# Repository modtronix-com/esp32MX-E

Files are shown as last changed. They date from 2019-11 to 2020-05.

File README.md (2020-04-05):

# esp32MX-E
This repository contains [documentation](docs), [examples](examples), [schematic, PCB files](pcb) and other information for the Modtronix esp32MX-E board. This board was initially launched on [Crowd Supply](https://www.crowdsupply.com/modtronix/esp32mx-e). It can be [ordered online](https://www.modtronix.com/esp32mx-e) from Modtronix<br>

After that, it will be available on www.modtronix.com, and most likely also for sale at www.mouser.com

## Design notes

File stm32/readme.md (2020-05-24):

This folder contains STM32 projects.
- The "default_ws" folder is a workspace for the STM32CubeIDE. It contains a single
  project named "default". This contains the default firmware for the STM32F030

## Modify STM32 project ##
To modify, build and program a STM32 project:
- Download and install the [STM32CubeIDE](https://www.st.com/en/development-tools/stm32cubeide.html).
- Start STM32CubeIDE, and select the "default_ws" folder as the workspace
- Select "File"->"Import" from the menu, and select "Existing project into workspace"
- Select the "default" project. In "Options" ensure "Copy project into workspace" is NOT selected
- Import project

This will import the "default" project into the workspace. It should now be possible to build the project, and program the STM32F030.

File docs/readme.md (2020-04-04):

Documentation for the Modtronix esp32MX-E board.

The esp32MX-E is a versatile ESP32 based board with support for Ethernet, WiFi, Bluetooth, USB Type C, and more. It is designed with ease-of-integration in mind, so you can use it to simplify and accelerate the development of your own custom boards. 

# Schematics & Dimensions
The esp32MX-E schematics & dimensions are available in the "images" folder:
- [Schematics Page1](../images/esp32MX-E_schematics_pg1.png?raw=true)
- [Schematics Page2](../images/esp32MX-E_schematics_pg2.png?raw=true)
- [Dimensions](../images/esp32MX-E_dimensions.png?raw=true)

# Power
The esp32MX-E has an advanced power supply circuit that accommodates multiple inputs, provides 3.3 V and 5 V outputs, and delivers over 2 A of current to the user. It has high current switch mode regulators, at both 3.3 V and 5 V, to ensure low power consumption and high efficiency. Power can be supplied via the USB C connector, a 2.1 mm barrel connector, or the external power supply pin. This allows board designers to integrate the esp32MX-E as a daughterboard and get 3.3 V, 5 V, and supply voltage via the pin header connector.

# Reliability
Capacitors, in particular, are often the cause of failure in electronic devices. We have sourced the capacitors in esp32MX-E from reputable manufacturers like Panasonic, Samsung, Murata, TDK, and Yageo. Furthermore, all of our capacitor voltages are overrated by at least 190%.

# User I/O
esp32MX-E has a secondary 32-bit ARM processor (STM32F030F4) that serves by default as an I²C port expander. If required, you can program this secondary microcontroller with custom firmware.

# Features & Specifications

- **esp32 Module**
    - 32-bit LX6 microprocessor operating at 160 or 240 MHz
    - 4 MB Flash
    - 520 KB SRAM
- **Storage**: Micro SD card slot
- **Wi-Fi**: 802.11 b/g/n
- **Bluetooth**: v4.2 BR/EDR & BLE
- **USB**: Type C connector
    - Virtual COM port via USB
    - Programmable via USB
    - Power via USB
- **User I/O**:
    - 22 pins of which 4 are inputs only.
    - Four 5 V tolerant I/O pins
    - Not all I/Os are available when the SD Card is used
    - Programmable pull-up and pull-down resistors on most inputs
- **Secondary Processor**: I²C I/O expander implemented with a user programmable STM32F030F4
- **Expansion Pin Headers**: Two standard 2.54 mm (0.1") expansion pin headers
    - One with 14 pins (2x7)
    - One with 20 pins (2x10)
- **Power Supply**: Switch Mode
    - 5 V, over 2 A of current for user applications
    - 3.3 V, over 2 A of current for user applications
- **Power Sources**:
    - USB Type C connector
    - 2.1 mm barrel connector
    - Vx external power supply pin
- **Supply Voltage**: 4.5 V to 16 V (via 2.1 mm Barrel connector or Vx pin)
- **Operating Temperature**:
    - Standard version: 0° C to 85° C
    - Industrial version: -40° C to 85° C
- **Physical Controls**:
    - User LED
    - Button
- **Compact Size**: 64.4 mm x 42 mm (2.54" x 1.65")
- **Enclosure**: Optional

# Integration into Custom Hardware
Designed both for standalone use and for integration into larger projects, esp32MX-E has two female headers, so you can plug a small expansion board into it or use esp32MX-E itself as a daughterboard. All connectors, switches and LEDs are on one side of the board, which makes it far easier to design custom enclosures.

We supply raised male headers, for when esp32MX-E is used as a daughterboard, that provide 14.5 mm of space between it and the baseboard. A single board spacer and a screw are all you need for a secure fit, and we provide both a threaded and a non-threaded 14.5 mm spacer. Two additional screw holes are available, but are not required when using esp32MX-E as a daughterboard.

The Eagle Schematics and PCB files for all prototype boards and faceplates are available in [in the PCB folder](../pcb).

| | |
| --- | --- |
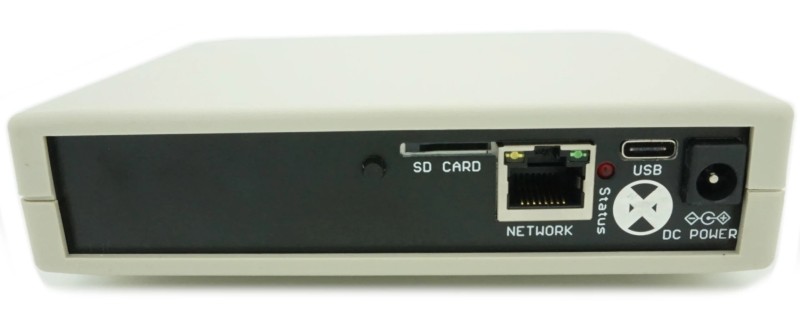
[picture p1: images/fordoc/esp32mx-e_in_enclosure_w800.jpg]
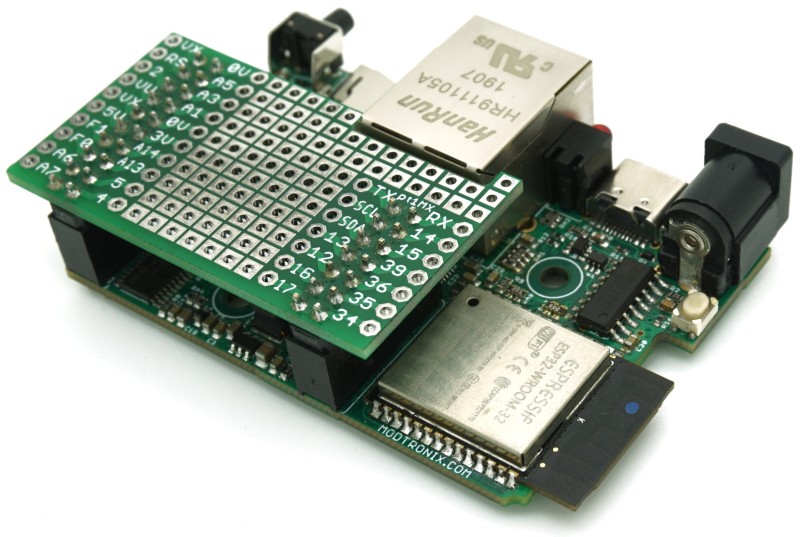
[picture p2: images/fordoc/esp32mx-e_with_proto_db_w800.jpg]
|  |  |
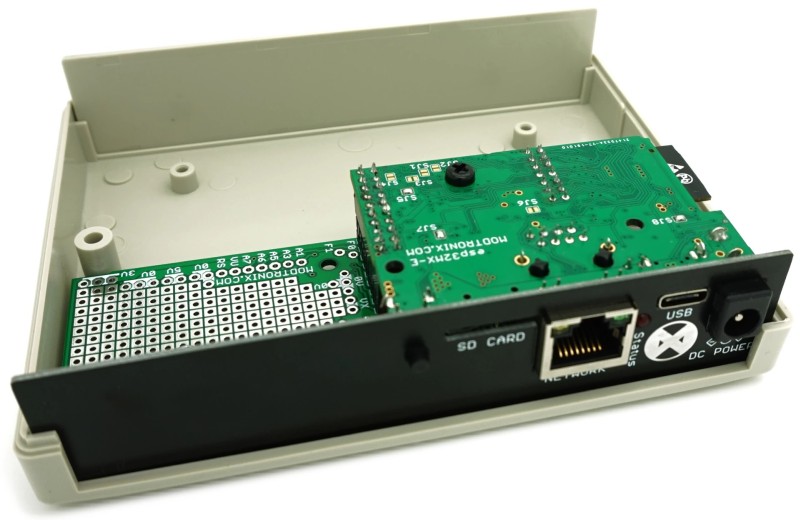
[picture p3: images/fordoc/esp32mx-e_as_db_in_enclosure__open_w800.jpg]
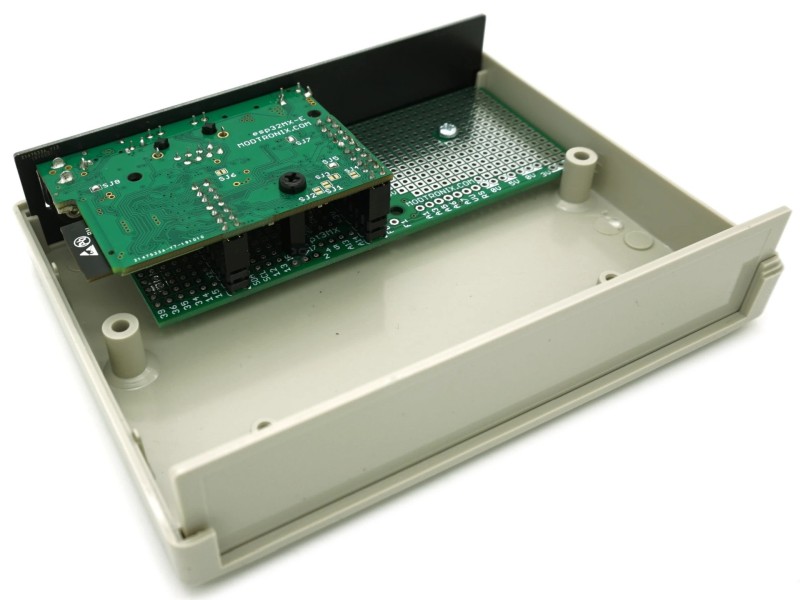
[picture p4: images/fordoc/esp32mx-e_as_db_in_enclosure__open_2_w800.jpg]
|  |  |

# Software Development
The two most popular ways to develop software for the esp32MX-E is using the official "Espressif ESP-IDF" or Arduino. The Arduino option is by far the easyest to get started. But, ESP-IDF provided many more options, and a true RTOS environment.

## Espressif ESP-IDF
For details to use the official ESP-IDF with the esp32MX-E, see [the "idf" examples folder](../examples/idf/README.md).

## Arduino
For details to use the official ESP-IDF with the esp32MX-E, see [the "idf" examples folder](../examples/arduino/README.md).

# STM32F030 Secondary Microcontroller
The esp32MX-E has a secondary STM32F030F4 microcontroller. It controls the PHY reset circuitry, and provides additional I/O via the the I2C port of the ESP32. It can also be programmed with custom firmware.

## Programming the STM32F030
The STM32F030F4 can be programmed via the following methods:
- Serial Port Bootloader
- ST-Link programmer
- By the host ESP32
See below for details.

### Serial Bootloader
The STM32 microcontroller has a built in serial(UART) bootloader, that is activated by pressing the user button while applying power to the esp32MX-E board. Once in the bootloader mode, we need a method to connect to the UART on the STM32. A simple way to do this is to have software on the ESP32 act as a bridge between the STM32 and virtual comm port chip. This enables us to use the STM32CubeProgrammer (STM32CubeProg) to program the STM32 via the UART. For this to work, the UART on the ESP32 has to be configured for 115200 baud, **even** parity, and 1 stop bit.

After programming the STM32 with the STM32CubeProgrammer, we can use this same setup to communicate with the UART on the STM32 via a serial port terminal. This is very useful for debugging. **Note** that the UART on the STM32 has to be configured for 115200 baud, **even** parity, and 1 stop bit. This is to match the settings required by the STM32CubeProgrammer, and which we used for our ESP32 bridge firmware.

### ST-Link Programmer
To program an STM32 chip using a ST-Link programmer, we need to connect the GND, Reset, SWDIO and SWCLK of the STM32 chip to the corresponding pins of the ST-Link programmer. These pins are all available available on the pin header of the esp32MX-E.

To get access to the UART on the STM32 during programming and debugging, we can use one of the following methods:
- Configure pins PA9 and PA3 of the STM32 as the UART TX and RX pins. These pins are available via the SCL(conected to PA9 of STM32) and PA3 pins on the pin header of the esp32MX-E board. When using the ST-Link V3, these pins can be connected to the RX and TX pins of the ST-Link programmer
- Configure pins PA9 and PA10 of the STM32 as the UART TX and RX pins. Then, program the ESP32 with firmware that acts as a bridge between the STM32 UART and USB virtual comm port chip. This will enable communicating with the STM32's UART via the USB virtual comm port.

### ESP32 programming the STM32
It is possible for the ESP32 to directly program the STM32 via it's UART bootloader. The ESP32 is connected to the STM32 via I2C. We have to add an I2C command to put the STM32 into bootloader mode. After doing this, the ESP32 will reconfigure the I2C pins connected to the STM32 to a UART. This is possible, seeing that the I2C and UART of the STM32F030 use the same pins. So, during normal operation, these pins on the STM32 are I2C pins, and when starting the STM32 in bootloader mode, they are UART pins.

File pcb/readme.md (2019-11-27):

This folder contains Eagle PCB and Schematic files. They are all provided for fee, as is. We take no responsibility for any errors
or defects.

The folders contains the following.

# pt1mx
This folder contains a small prototype PCB that first onto the 2 female headers of the esp32MX-E board.

| | |
| --- | --- |
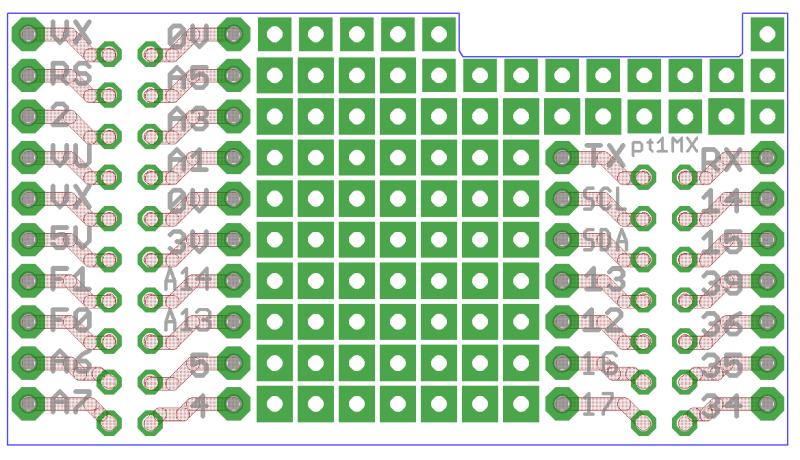
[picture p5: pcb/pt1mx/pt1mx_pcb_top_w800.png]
|  | Image of pt1mx |

# pt2mx
This folder contains a larger prototype PCB that first onto the 2 female headers of the esp32MX-E board.
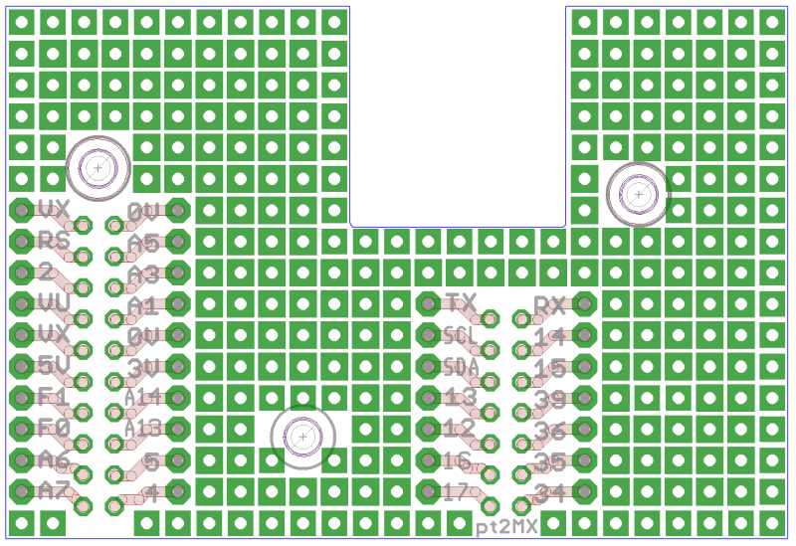
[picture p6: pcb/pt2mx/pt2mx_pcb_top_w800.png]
Image of pt2mx


# pt3mx
This folder contains a baseboard for the esp32MX-E board. It is designed to be used with raised 2x7 and 2x10 male
pin headers(standard 0.1" = 2.54mm spacing). We use 14.5mm raised headers, and also have 14.5mm high PCB spacers
available. It fits into the Hammond RM2015S enclosure. The "fp_pt3mx" front panel can be used with the RM2015S
enclosure.

| | |
| --- | --- |
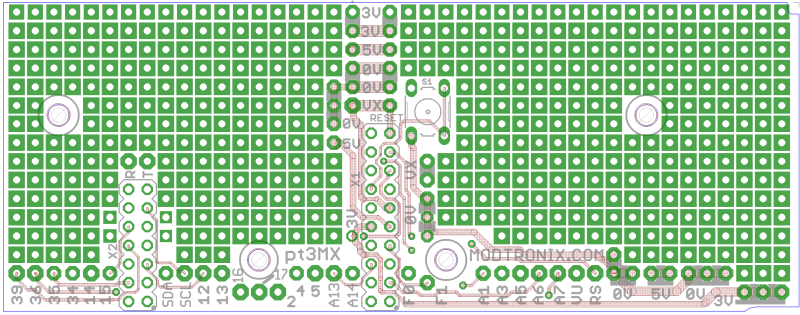
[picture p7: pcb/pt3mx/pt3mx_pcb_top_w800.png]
Image of pt3mx
|  | Image of pt1mx |

# fpan-mxe
This folder contains the frontpanel used when the esp32MX-E is used together with the pt3mx(or custom board) baseboard, and the RM2015S
enclosure. This frontpanel is a standard PCB (1 or 2 layers), with black solder mask. By default, we get them manufactured using HASL(Hot Air Solder Level) surface finish. For a bit extra, you can get it manufactured with the ENIG(Immersion Gold) surface finish, which adds a premium look.

| | |
| --- | --- |
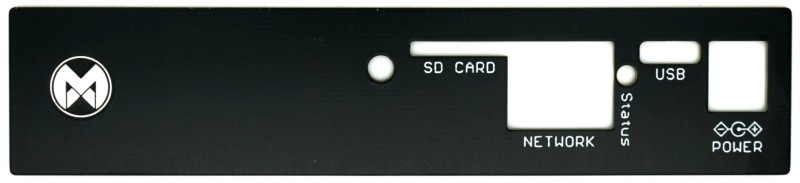
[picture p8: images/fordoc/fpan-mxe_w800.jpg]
Image of pt1mx
|  | Image of pt1mx |

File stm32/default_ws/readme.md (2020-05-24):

This folder is a [STM32CubeIDE](https://www.st.com/en/development-tools/stm32cubeide.html) workspace, containing a single project named "default". It contains the default firmware for the STM32F030

This code performs the following main functions:
- Monitors the ESP32 reset pin. If a reset is applied(via reset button on the esp32MX-E or USB programming), it resets the PHY chip(LAN8720)
- Checks when the ESP32 starts outputting the 50MHz PHY clock on the GPIO0 pin, and takes the PHY out of reset.

This the code monitors the GPIO0 pin of the ESP32. This pin will output the 50MHz PHY clock once the ESP32 is configured for Ethernet. If 200 or more pulses are found on the GPIO0 pin within 3ms, the PHY is taken out of reset. The reason we check for 200 pulses in 3ms is to enable GPIO0 to be used to blink the LED when Ethernet is NOT enabled. This allow the esp32MX-E board to be programmed with code that does not use Ethernet, and uses GPIO0 to blink the LED.

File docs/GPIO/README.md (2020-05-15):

# Pinouts & GPIO Pins #
For details on the ESP32 GPIO ports, see the [ESP32 GPIO](#esp32-gpio) section below.  
For details on the STM32F030 GPIO ports, see the [STM32F030 GPIO](#stm32f030-gpio) section below.
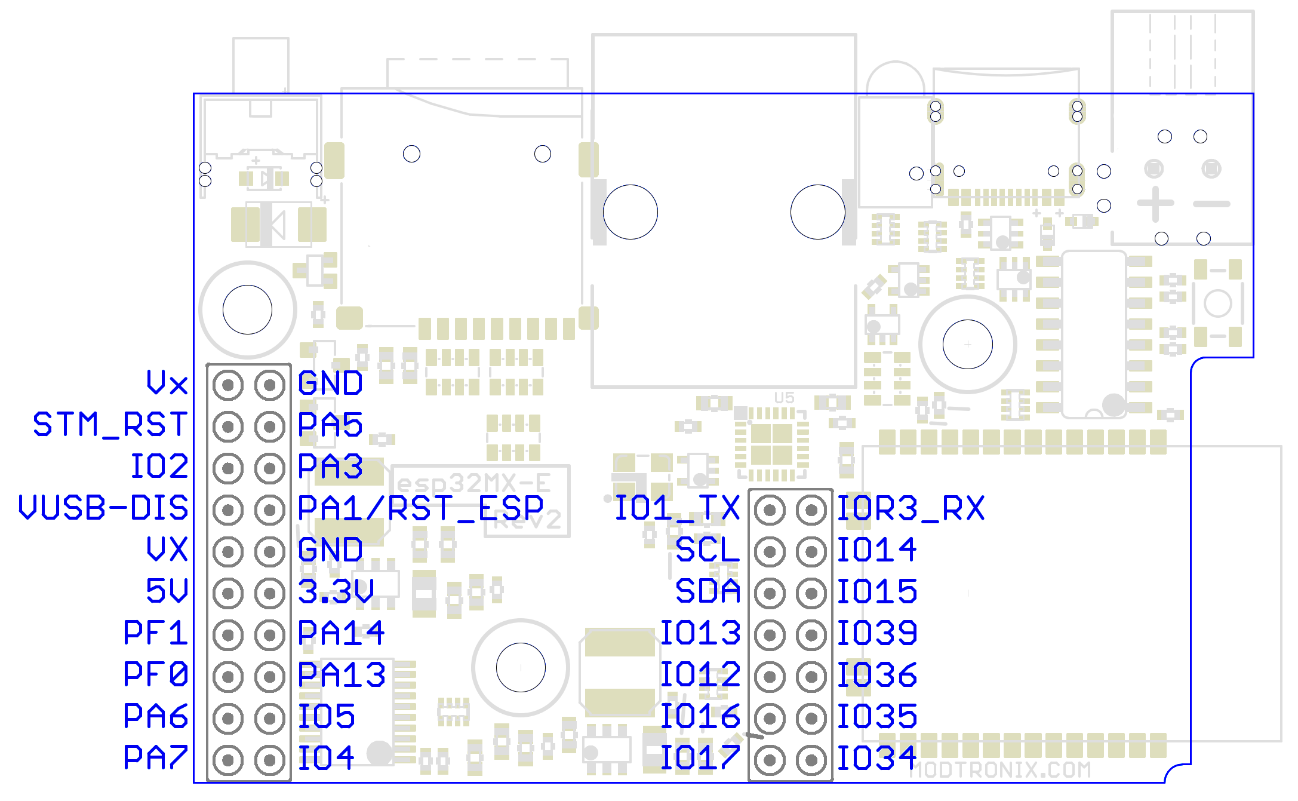
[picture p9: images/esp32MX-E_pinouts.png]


# ESP32 GPIO

| ESP32 Pin | Analog | DAC/T | Serial | Function | Note |
| --- | --- | --- | --- | --- | --- |
| GPIO0  | ADC2-1  | Touch-1 | | **NOT available** if Ethernet used, used by Bootloader and PHY | Default **Pull-Up**. Bootloader Mode=0, Run Mode=1 |
| GPIO1  | | | TX0 | **Available** if USB comm not used. USB TX.| On the ESP32-NodeMCU, this pin is used for the USB to Serial converter TX pin |
| GPIO2  | ADC2-2  | Touch-2 | | **Available** if SD not used. SD Card. 47k PU| Default **Pull-Down**. Must be 0 to enter Bootloader Mode (when GPIO0=0). |
| GPIO3  | | | RX0 | **Available** if USB comm not used. USB RX via jumper. | On the ESP32-NodeMCU, this pin is used for the USB to Serial converter RX pin |
| GPIO4  | ADC2-0  | Touch-0 | | **Available** to user. | | 
| GPIO5  | | | VSPI-SS | **Available** by default, LED via Jumper | Default **Pull-up**, use to determine timing of SDIO Slave. |
| GPIO12 | ADC2-5  | Touch-5 | MISO | **Available** to user. | **JTAG** TDI - Default **Pull-down**. If 1 at PU, sets flash = 1.8V, else standard 3.3V. **MUST be 0** at PU for 3.3V board! |
| GPIO13 | ADC2-4  | Touch-4 | MOSI | **Available** to user. | **JTAG** TCK |
| GPIO14 | ADC2-6  | Touch-6 | CLK | **Available** if SD not used.<br>SD Card.| **JTAG** TMS |
| GPIO15 | ADC2-3  | Touch-3 | SS | **Available** if SD not used.<br>SD Card.| **JTAG** TDO - Default **Pull-up**. If 0 at PU, silences boot messages printed by the ROM bootloader.|
| GPIO16 | | | RX2 | **Available** to user. | **NOT AVAILABLE** on Wrover, used for PSRAM CS ! |
| GPIO17 | | | TX2 | **Available** to user. | **NOT AVAILABLE** on Wrover, used for PSRAM CLK ! |
| GPIO18 | | | VSPI-CLK  | **NOT available**, used by PHY | |
| GPIO19 | | | VSPI-MISO | **NOT available**, used by PHY | |
| GPIO21 | | | I2C-SDA | **NOT available**, used by PHY | |
| GPIO22 | | | I2C-SCL | **NOT available**, used by PHY | |
| GPIO23 | | | VSPI-MOSI | **NOT available**, used by PHY | |
| GPIO25 | ADC2-8  | DAC 1 | | **NOT available**, used by PHY | |
| GPIO26 | ADC2-9  | DAC 2 | | **NOT available**, used by PHY | |
| GPIO27 | ADC2-7  | Touch-7 | | **NOT available**, used by PHY | |
| GPIO32 | ADC1-4  | Touch-9 | | I2C SCL, can also be<br> **used for user I2C** |  |
| GPIO33 | ADC1-5  | Touch-8 | | I2C SCL, can also be<br> **used for user I2C** |  |
| GPIO34 | ADC1-6  | | | **Available** by default,<br> User Button via Jumper | **Input Only!** No PU or PW! |
| GPIO35 | ADC1-7  | | | **Available** to user.<br> Input only | **Input Only!** No PU or PW! |
| GPIO36 | ADC1-0  | | | **Available** to user.<br> Input only | **Input Only!** No PU or PW! |
| GPIO39 | ADC1-3  | | | **Available** to user.<br> Input only | **Input Only!** No PU or PW! |

## Other Pins that are not available ##
| ESP32 Pin | Analog | DAC/T | Serial | NodeMCU | Wrover | Note |
| --- | --- | --- | --- | --- | --- | --- |
| GPIO6  | | | | | N/A | **NOT AVAILABLE** used for SPI Flash Wrover/Wroom Modules |
| GPIO7  | | | | | N/A | **NOT AVAILABLE** used for SPI Flash Wrover/Wroom Modules |
| GPIO8  | | | | | N/A | **NOT AVAILABLE** used for SPI Flash Wrover/Wroom Modules |
| GPIO9  | | | RX1 | | N/A | **NOT AVAILABLE** used for SPI Flash Wrover/Wroom Modules |
| GPIO10 | | | TX1 | | N/A | **NOT AVAILABLE** used for SPI Flash Wrover/Wroom Modules |
| GPIO11 | | | | | N/A | **NOT AVAILABLE** used for SPI Flash Wrover/Wroom Modules |
| GPIO16 | | | RX2 | | | **NOT AVAILABLE** on Wrover, used for PSRAM CS ! |
| GPIO17 | | | TX2 | | | **NOT AVAILABLE** on Wrover, used for PSRAM CLK ! |
| GPIO37 | | | | N/A | N/A | Pin is NOT available on NodeMCU and Wrover boards! |
| GPIO38 | | | | N/A | N/A | Pin is NOT available on NodeMCU and Wrover boards! |

## Input Only Pins: 34-39 ##
Pins 34, 35, 36, 37, 38 and 39 cannot be configured as outputs, but they can be used as either digital inputs, analog inputs, or for other unique purposes. Also note that they do not have internal pull-up or pull-down resistors, like the other I/O pins.

GPIO pins 36-39 are an integral part of the ultra low noise pre-amplifier for the ADC – they are wired up to 270pF capacitors, which help to configure the sampling time and noise of the pre-amp.

## Pin Matrix ##
The ESP32 has a pin matrix allowing any of the I/O pins to be assigned following peripherals:
  * 3 x SPI interfaces
  * 3 x UART interfaces
  * 2 x I2C interfaces
  * 2 x I2S interfaces
  * 16 x PWM outputs

## ADC ##
See ADC pins in table above.

## UART ##
The ESP32 has 3 UART interfaces (0,1 and 2), which provide asynchronous communication (RS232 and RS485) and IrDA support.
Communication speed is up to 5 Mbps. All UARTs provides hardware management of the CTS and RTS signals and software flow
control (XON and XOFF). All of the interfaces can be accessed by the DMA controller or directly by the CPU.

## SPI, HSPI and VSPI ##
The ESP32 has 4 SPI peripherals(SPI0, SPI1, HSPI and VSPI), of which 2(HSPI and VSPI) are available to the user.

SPI Peripherals can be configured for slave and master modes in 1-line full-duplex and 1/2/4-line half-duplex communication modes. 
They support the following general-purpose SPI features:
  * Four timing modes of the SPI format transfer, which depend on the polarity (POL) and the phase (PHA)
  * up to 40 MHz and the divided clocks of 80 MHz
  * up to 64-byte FIFO
  * Each SPI can be served by DMA

SPI0 and SPI1 are used for the external Flash, and are not available to the user!
This leaves two SPI peripherals for general use, HSPI and VSPI. They have default pins(IOMUX pins), but can also be assigned to any other
I/O pin using the Pin Matrix. When using the default pins, speeds up to 80MBits/sec is possible, where 40MBits/sec is the limit when
using the pin matrix. For details, see [[https://docs.espressif.com/projects/esp-idf/en/latest/api-reference/peripherals/spi_master.html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|this page]].

The default pins for HSPI are:
  * SS = GPIO 15
  * CLK = GPIO 14
  * MISO = GPIO 12
  * MOSI = GPIO 13

The default pins for VSPI are:
  * SS = GPIO 5
  * CLK = GPIO 18
  * MISO = GPIO 19
  * MOSI = GPIO 23

## I2C ##
The ESP32 has two I2C bus interfaces which can serve as I2C master or slave, depending on the user’s configuration.
The I2C interfaces support:
  * Standard mode (100 kbit/s)
  * Fast mode (400 kbit/s)
  * Up to 5 MHz, yet constrained by SDA pull-up strength
  * 7-bit/10-bit addressing mode
  * Dual addressing mode 
Users can program command registers to control I2C interfaces, so that they have more flexibility.

## I2S ##
Two standard I2S interfaces are available in ESP32. They can be operated in the master or slave mode, in full
duplex and half-duplex communication modes, and can be configured to operate with an 8-/16-/32-/40-/48-bit
resolution as input or output channels. BCK clock frequency, from 10 kHz up to 40 MHz, is supported. When one
or both of the I2S interfaces are configured in the master mode, the master clock can be output to the external
DAC/CODEC.
Both of the I2S interfaces have dedicated DMA controllers. PDM and BT PCM interfaces are supported.

## PWM ##
The Pulse Width Modulation (PWM) controller can be used for driving digital motors and smart lights. The controller
consists of PWM timers, the PWM operator and a dedicated capture sub-module. Each timer provides timing in
synchronous or independent form, and each PWM operator generates a waveform for one PWM channel. The
dedicated capture sub-module can accurately capture events with external timing.

## LED PWM ##
The LED PWM controller can generate 16 independent channels of digital waveforms with configurable periods
and duties. The 16 channels of digital waveforms operate at 80 MHz APB clock, eight of which have the option of using the 8
MHz oscillator clock. Each channel can select a 20-bit timer with configurable counting range, while its accuracy
of duty can be up to 16 bits within a 1 ms period.
The software can change the duty immediately. Moreover, each channel supports step-by-step duty increasing or
decreasing automatically, which makes it useful for the LED RGB color-gradient generator.

## Touch Sensor ##
The ESP32 has 10 capacitive sensing GPIOs.

## Buttons and LEDs ##
By default, GPIO5 is used for the user LED, and GPIO34 for the user button. Both these are enabled
via solder jumpers on the back of the board, and can be disabled by opening the solder jumper. Both the LED and user button are also connected to port pins on the STM32F030, and can be controlled via it, thus freeing GPIO5 and GPIO34 of the ESP32 chip.

## JTAG Pins ##
Pins 12 to 15 are also used for JTAG functions. If JTAG debugging is required, these pins should be used in such a way that they will be
available for the JTAG programmer/debugger.

## ESP32 Strapping Pins ##
**GPIO0**, **GPIO5** and **GPIO15** have pull-**up** resistors enabled during power up.\\
**GPIO2** and **GPIO12** have pull-**down** resistors enabled during power up.\\
These pull-up and pull-down resistors can be disabled via software once the device is running.

The ESP32 will enter the serial bootloader when GPIO0 is held low on reset. Otherwise it will run the program in flash.

GPIO0 has an internal pullup resistor, so if it is left unconnected then it will pull high.

Many boards use a button marked "Flash" (or "BOOT" on some Espressif development boards) that pulls GPIO0 low when pressed.

GPIO2 must also be either left unconnected/floating, or driven Low, in order to enter the serial bootloader.

## EN(RST) Pin ##
The EN pin is the 3.3V regulator’s enable pin. It’s pulled up, so connect to ground to disable the 3.3V regulator. This means that you can use
this pin connected to a push button to restart your ESP32, for example. This pin does NOT go low during a software reset of the ESP32.

# STM32F030 GPIO
The STM32F030 can be used for general purpose IO.

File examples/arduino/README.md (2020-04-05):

# Examples using Arduino IDE
This folder contains examples using Arduino for ESP32. For details, see [Github.com/espressif/arduino-esp32](https://github.com/espressif/arduino-esp32)

## Installation
The examples provided in this folder have been build using [v1.0.4](https://github.com/espressif/arduino-esp32/releases/tag/1.0.4) of Arduino-ESP32, which uses v3.2 of the Espressif ESP-IDE. For details on installing it, see this page:  
https://github.com/espressif/arduino-esp32#installation-instructions  

In addition, we also used VS Code, with the Microsoft Arduino Plugin.

## Usage
In the Tools menu of the Arduino IDE, select the "ESP32 Pico Kit" board. We might add the "esp32MX-E" board to future versions of Arduino ESP32, but currently it is not required.

## Additional Modifications
The followig can be done to have the esp32MX-E listed as an available board in the Tools menu of the IDE, but it is NOT required. As mentioned above, using the "ESP32 Pico Kit" board works fine.   

Currently the Arduino-ESP32 board manager does not list the esp32MX-E as an available board by default. To add it to the list of available boards in the Arduino IDE(in Tools menu), the following can to be done:
- After installing the Arduino IDE and the Arduino-ESP32 board, locate the "boards.txt" file in the ESP32 folder. It will be located in the following folder of your Arduino installation: "..\packages\esp32\hardware\esp32\1.0.4"
- Add the code given below to the end of this file(or to top of file after ").

```
esp32mx-e.name=Modtronix ESP32MX-E

esp32mx-e.upload.tool=esptool_py
esp32mx-e.upload.maximum_size=1310720
esp32mx-e.upload.maximum_data_size=327680
esp32mx-e.upload.wait_for_upload_port=true

esp32mx-e.serial.disableDTR=true
esp32mx-e.serial.disableRTS=true

esp32mx-e.build.mcu=esp32
esp32mx-e.build.core=esp32
esp32mx-e.build.variant=esp32mx-e
esp32mx-e.build.board=ESP32MX-E

esp32mx-e.build.f_cpu=240000000L
esp32mx-e.build.flash_mode=dio
esp32mx-e.build.flash_size=4MB
esp32mx-e.build.boot=dio
esp32mx-e.build.partitions=default
esp32mx-e.build.defines=

esp32mx-e.menu.FlashFreq.80=80MHz
esp32mx-e.menu.FlashFreq.80.build.flash_freq=80m
esp32mx-e.menu.FlashFreq.40=40MHz
esp32mx-e.menu.FlashFreq.40.build.flash_freq=40m

esp32mx-e.menu.UploadSpeed.921600=921600
esp32mx-e.menu.UploadSpeed.921600.upload.speed=921600
esp32mx-e.menu.UploadSpeed.115200=115200
esp32mx-e.menu.UploadSpeed.115200.upload.speed=115200
esp32mx-e.menu.UploadSpeed.256000.windows=256000
esp32mx-e.menu.UploadSpeed.256000.upload.speed=256000
esp32mx-e.menu.UploadSpeed.230400.windows.upload.speed=256000
esp32mx-e.menu.UploadSpeed.230400=230400
esp32mx-e.menu.UploadSpeed.230400.upload.speed=230400
esp32mx-e.menu.UploadSpeed.460800.linux=460800
esp32mx-e.menu.UploadSpeed.460800.macosx=460800
esp32mx-e.menu.UploadSpeed.460800.upload.speed=460800
esp32mx-e.menu.UploadSpeed.512000.windows=512000
esp32mx-e.menu.UploadSpeed.512000.upload.speed=512000

esp32mx-e.menu.DebugLevel.none=None
esp32mx-e.menu.DebugLevel.none.build.code_debug=0
esp32mx-e.menu.DebugLevel.error=Error
esp32mx-e.menu.DebugLevel.error.build.code_debug=1
esp32mx-e.menu.DebugLevel.warn=Warn
esp32mx-e.menu.DebugLevel.warn.build.code_debug=2
esp32mx-e.menu.DebugLevel.info=Info
esp32mx-e.menu.DebugLevel.info.build.code_debug=3
esp32mx-e.menu.DebugLevel.debug=Debug
esp32mx-e.menu.DebugLevel.debug.build.code_debug=4
esp32mx-e.menu.DebugLevel.verbose=Verbose
esp32mx-e.menu.DebugLevel.verbose.build.code_debug=5

##############################################################
```

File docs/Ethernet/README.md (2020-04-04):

# Ethernet
Ethernet is implemented with the internal Ethernet peripheral of the ESP32. The ESP32 is configured to output a 50MHz clock on the GPIO0 pin. The LAN8720 external PHY chip is used.

## Function of STM32F030
It is important that the PHY chip's reset pin only gets released once the ESP32 is outputting the 50MHz signal on GPIO0. This happens during the Ethernet initialization code. The STM32F030 performs this function. It will monitor the GPIO0 pin for a clock signal. If it detects more than 1000 cycles within a 10ms period, it will release the PHY from reset.

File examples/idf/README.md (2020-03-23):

# Examples using ESP-IDF
This folder contains examples using ESP-IDF, the official development framework for the ESP32 chip from Espressif(manufacturers of the ESP32). For details, see [github.com/espressif/esp-idf](https://github.com/espressif/esp-idf)

They have been built using **v4.0**, with Long Term Support by Espressif. For details on installing the development environment, see this page:  
https://docs.espressif.com/projects/esp-idf/en/v4.0/get-started/index.html  
It might also work with the latest stable realease. We have however currently only tested it with v4.0:  
https://docs.espressif.com/projects/esp-idf/en/stable/get-started/

As mentioned in the "Get ESP-IDF" section, the best way to get it is to use the GIT command:  
`git clone -b v4.0 --recursive https://github.com/espressif/esp-idf.git`

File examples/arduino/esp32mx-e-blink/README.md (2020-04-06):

# Blink Example

Very simple examples that blinks the LED on the esp32MX-E.
It also sends a message via the serial port if the button is pressed.

IMPORTANT! This example only works with esp32MX-E boards with the latest STM32F030 firmware.
See "Details" sectioin below

When Ethernet is not used, GPIO 0 should be used for controlling the LED. If Ethernet
is enabled, GPIO 5 should be used. This is due to the Ethernet PHY reset, and clock detection
circuitry on the esp32MX-E. But, when using GPIO 5, the LED will never completly turn off, and
will toggle between low and high bright levels.

## Details ##
This example only works with esp32MX-E boards with the latest STM32F030 firmware.
When Ethernet is enabled, the 50MHz clock pulse will be outputted on GPIO0. The STM32F030
has code that monitors GPIO0, and after detecting 2000 clock pulses, will enable the Ethernet
PHY chip(LAN8720). On the old STM32F030 firmware, it enabled the PHY after detecting 2000 pulses.
On the new STM32F030 firmware, these 2000 pulses have to occur within 2ms. This means that GPIO0 can NOT be used to control the LED on boards with old STM32F030 firmware, seeing that after 2000 pulses, it will stop working. On these boards, GPIO5 should be used, see the "esp32mx-e-blink-old" example.

See the [README.md](../README.md) file in the upper level 'examples/idf' directory for more information about examples.

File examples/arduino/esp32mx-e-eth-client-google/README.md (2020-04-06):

Basic Ethernet client test. The esp32MX-E will connect to google, and print the resuls to a
terminal at 115200 baud.
  
This test requires the board is plugged into a network with a DHCP server. When running this
sketch, the esp32MX-E will connect to the DHCP server and obtain an IP address. It will then
attemp to connect to "google.com", and print the result to the terminal.

To test this sketch, do the following:
 - Install Arduino IDE
 - Install "Arduino ESP32" via the board manager (https://github.com/espressif/arduino-esp32#installation-instructions)
   This code was tested with v1.0.4 of "Arduino ESP32", which uses v3.2 of the Espressif ESP-IDE
 - Select the "ESP32 Pico Kit" board in the Arduino IDE
 - Plug the esp32MX-E into a network with a DHCP server, and connect to PC via USB
 - Verify and Upload this sketch
 - Start the Serial Monitor (in Tools menu)

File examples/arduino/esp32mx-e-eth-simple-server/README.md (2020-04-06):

Ethernet Web Server LED Blink

A simple web server that lets you blink an LED via the web.
This sketch will print the IP address of your esp32MX-E board(once connected)
to the Serial monitor. From there, you can open that address in a web browser
to turn on and off the LED on pin 5.

If the IP address of your shield is yourAddress:
http://yourAddress/H turns the LED on
http://yourAddress/L turns it off

To test this sketch, do the following:
 - Install Arduino IDE
 - Install "Arduino ESP32" via the board manager (https://github.com/espressif/arduino-esp32#installation-instructions)
   This code was tested with v1.0.4 of "Arduino ESP32", which uses v3.2 of the Espressif ESP-IDE
 - Select the "ESP32 Pico Kit" board in the Arduino IDE
 - Plug the esp32MX-E into a network with a DHCP server, and connect to PC via USB
 - Verify and Upload this sketch
 - Start the Serial Monitor (in Tools menu)

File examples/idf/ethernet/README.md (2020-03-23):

# Ethernet Example

This is a very basic Ethernet example. It will perform Ethernet initialization, and connect to a DHCP server on the network. Once it has connected to the server, it will print the IP address via the virtual COM port on the USB. You can ping the board using this IP address.

To view the output of the virtual COM port, connect the board to the USB port a PC. Look in the PC's device manager what serial port number is created for the virtual COM port. Start a serial port terminal app on the PC, and connect to that serial port using 115200 baud, 8-bit, no parity, and 1 stop and start bit.

## ESP-IDF
It was built and tested with v4.0 of ESP-IDF, the official development framework for the ESP32 chip from Espressif(manufacturers of theee ESP32). For details, see [github.com/espressif/esp-idf](https://github.com/espressif/esp-idf)

See the [README.md](../README.md) file in the upper level 'examples/idf' directory for more information about examples, and how to install ESP-IDF.

## Building and Flashing
See the "Getting Started" section in the [ESP-IDF guide](https://docs.espressif.com/projects/esp-idf/en/v4.0/get-started/index.html) for details how to build and flash the project. Basically, all that has to be done is:
- Install ESP-IDF v4.0 on your computer
- Start the "ESP-IDF Command Prompt", will be installed in step above
- Change working directory to this folder (../examples/idf/ethernet)
- Connect the esp32MX-E to a USB port on your PC. Note in device manager what virtual COM port is created for it. The next step assumes it is 5.
- Build the code, program the esp32MX-E board, and start the serial port monitor with the command(using your COM port number):  
`idf.py -p COM5 flash monitor`
- When done, the serial port monitor should start with debug output
- Connect the esp32MX-E to a network. A message should be printed in the serial port monitor, stating that a network cable was plugged in, and a DHCP connection made. The IP address assigned to the esp32MX-E will be given.

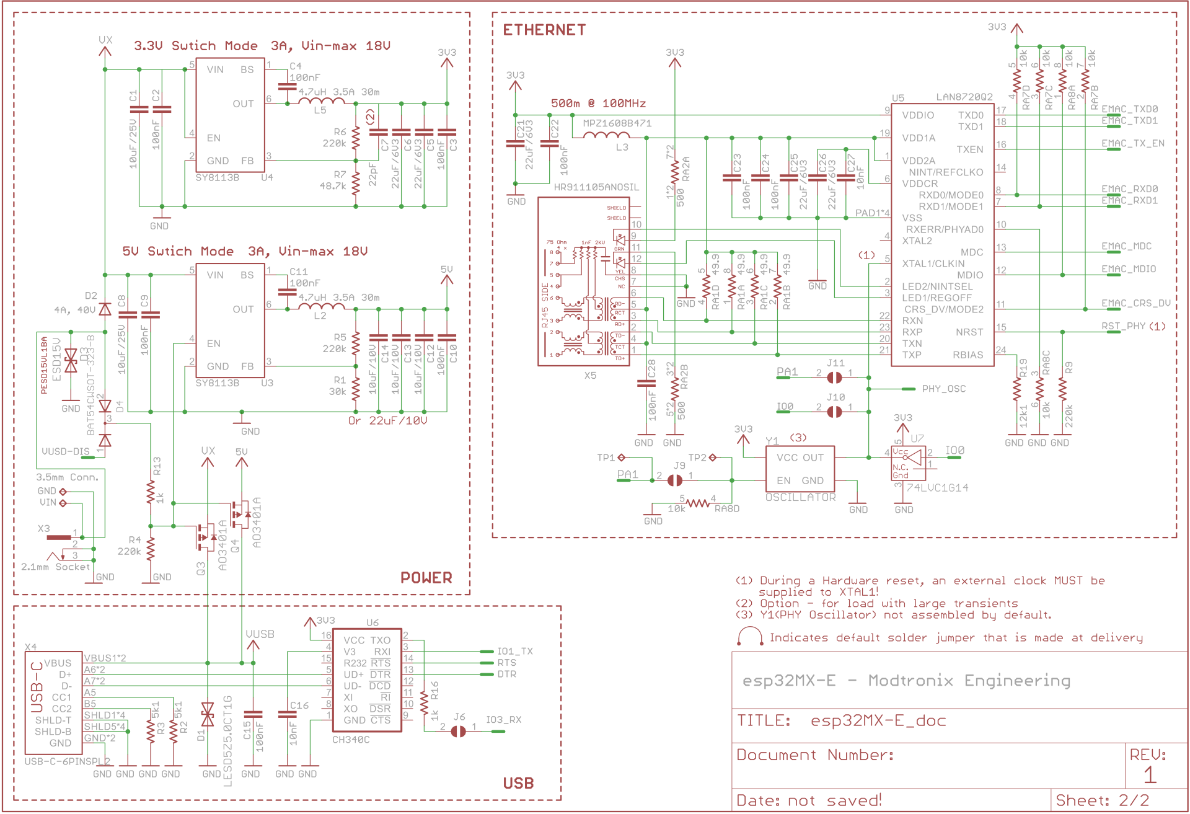
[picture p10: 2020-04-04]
images/esp32MX-E_schematics_pg2.png

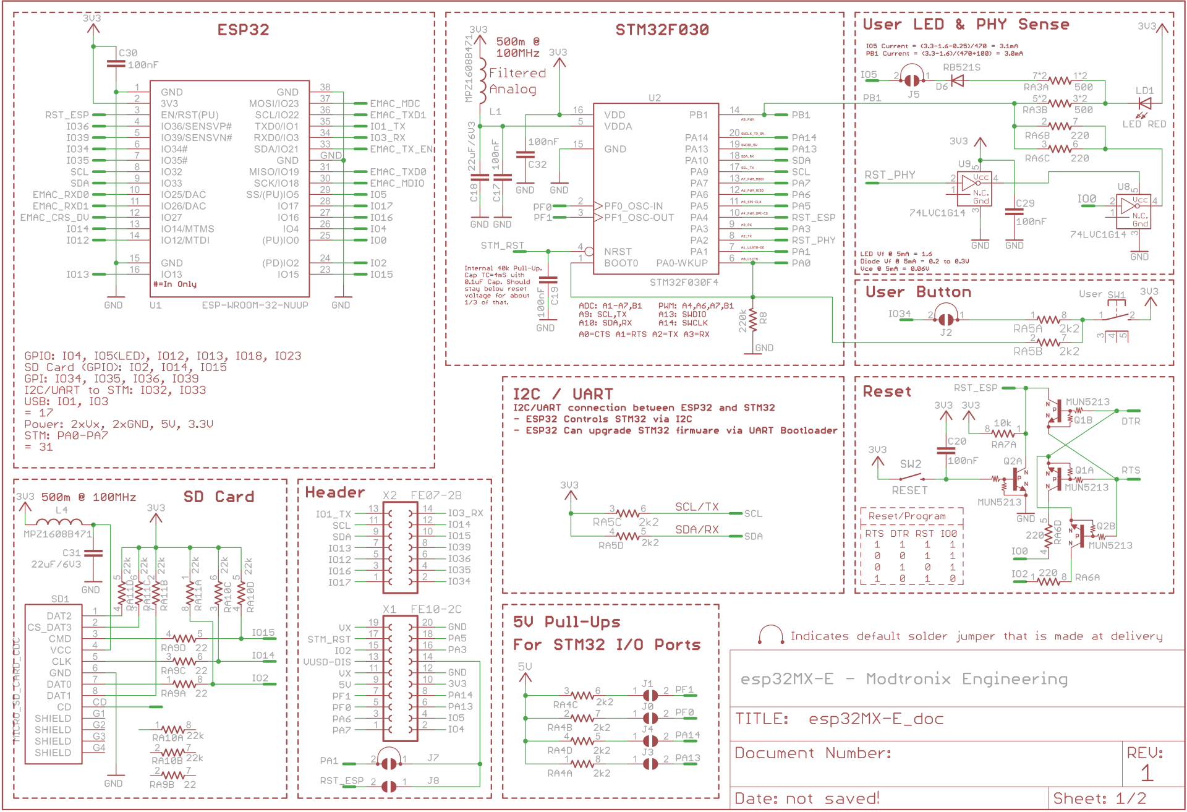
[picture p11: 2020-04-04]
images/esp32MX-E_schematics_pg1.png

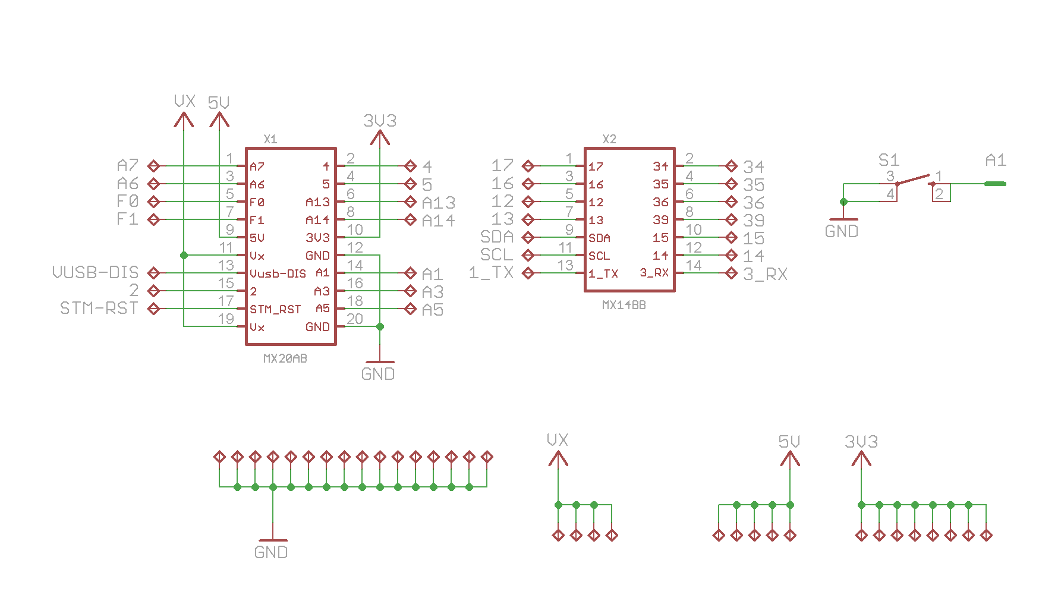
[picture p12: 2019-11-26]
pcb/pt3mx/pt3mx_schematics.png

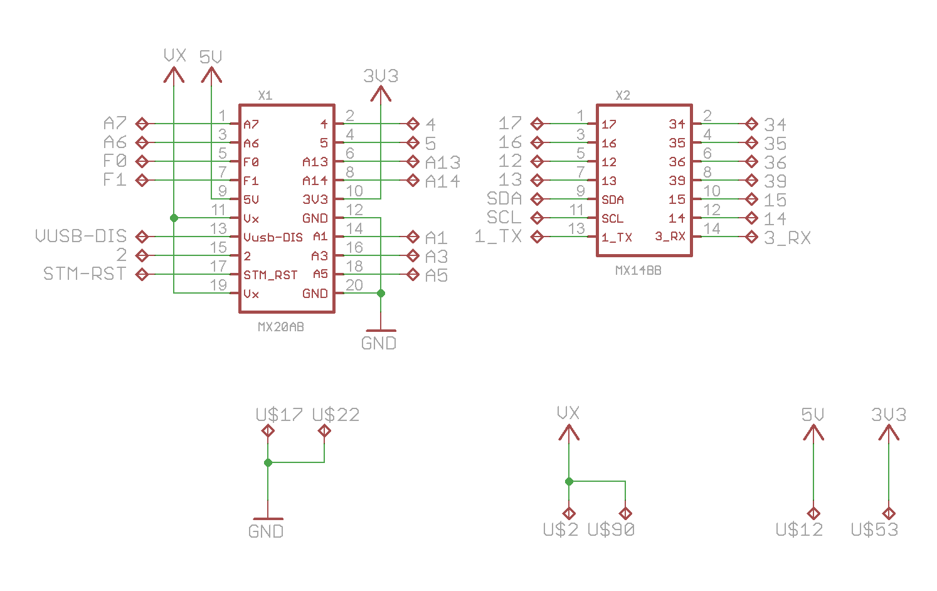
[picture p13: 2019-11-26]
pcb/pt2mx/pt2mx_schematics.png

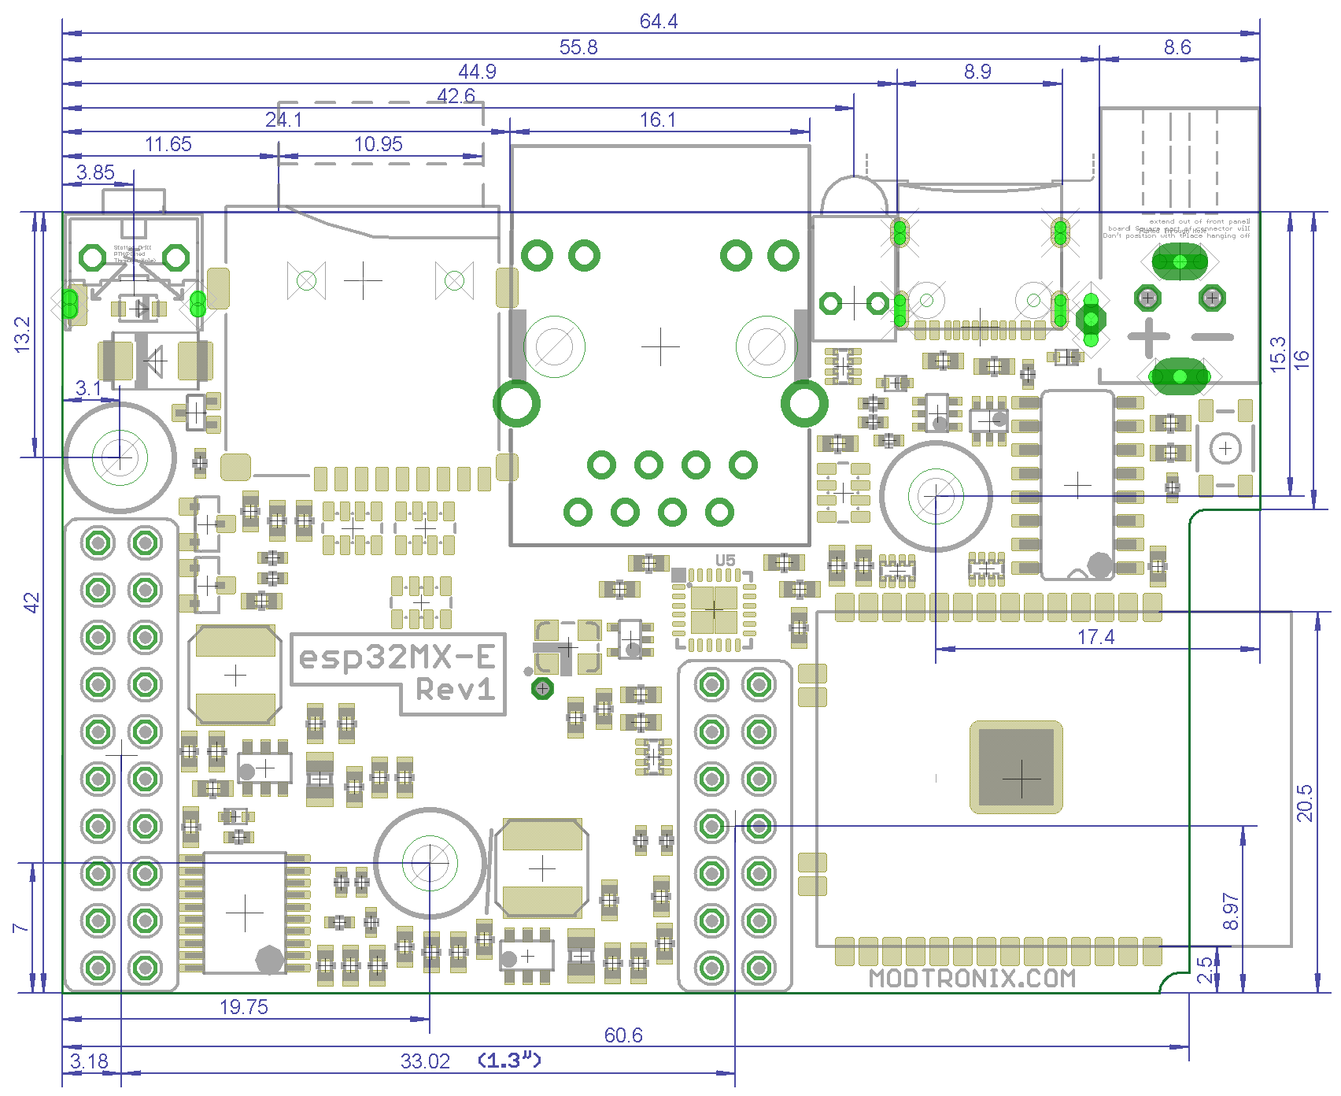
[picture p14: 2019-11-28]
images/esp32MX-E_dimensions.png

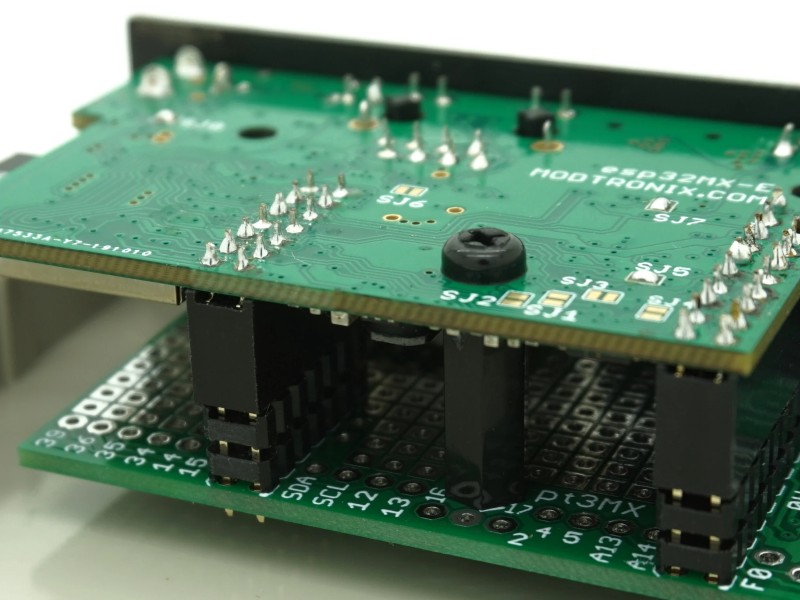
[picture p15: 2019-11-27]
images/fordoc/esp32mx-e_as_db_screw_w800.jpg

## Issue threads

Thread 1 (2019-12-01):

Pariently waiting info on the `esp32MX-EP` variant

kquinsland, 2019-12-01:
Hi.

This is not an "issue" in the strictest sense... I just didn't know where else i could "sign up" for a notification about the PoE variant.  If there's a better way to sign up  for notification about  when the PoE version is ready, i'm all ears.

modtronix-com, 2019-12-03:
Hi, sorry missed this "issue". I hope to have to PoE variant early next year. Should have prototypes end of January. Will launch it via Crowd Supply, so you can sign up to the project there once it is live.

blaudp79, 2019-12-14:
Hi, Same here. I'm looking to purchase the POE variant. I've read that you guys are swapping out the SD card reader for the POE circuit. If that is the case it would be nice to have an SD card add-on that can be mounted on the daughter board and it would have the cut-out on the black rear panel. It would be even better if If you could combine the SD card reader with a battery charging circuit as well on the same add-on board. I'm looking for both POE & SD card options. Removable cut out in the plastic enclosure for standard 1602 or 2004 LCD would also be a cool upgrade.

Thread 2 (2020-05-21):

STM32F030 standard firmware

yrashk, 2020-05-21:
Is there a plan to publish the code (or at the very least the blob) for the STM32F030 firmware the devices are shipped with?

modtronix-com, 2020-05-24:
Hi, just added the STM32 folder containing the STM32F030 firmware.

yrashk, 2020-05-24:
Thank you!

Closed 2020-05-24.

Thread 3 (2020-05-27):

STM32 serving as an I2C port expander

yrashk, 2020-05-27:
You mention STM32 being able to be used as a port expander by default (via I2C). Can you elaborate on this?

Neither the source code in `stm32` nor STM32F030 datasheet provide anything of value with respect to this.

Thank you!

modtronix-com, 2020-05-27:
Hello, this has to be implemented in the STM32. It will soon be added to the STM32 firmware. Basically the STM32 has to listen on the I2C port for messages send from the ESP32. I simple protocol is required to define how STM32 port pins can be read from and written to.

yrashk, 2020-05-27:
Thank you! I guess I was confused by the wording

> esp32MX-E has a secondary 32-bit ARM processor (STM32F030F4) that **serves by default** as an I²C port expander

(emphasis mine)

I initially assumed that your default hardware had this implemented (but I didn't find this in the source as right now the main loop of that firmware is much simpler than that).

Again, thank you! :)

skiizo, 2020-10-23:
I'm needing the I2C port expander capability too.  Any timeline for this??

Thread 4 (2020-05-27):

Activating STM32's bootloader

yrashk, 2020-05-27:
Hi again :)

I am trying to figure STM32 bootloader activation. Following the information found in datasheets, I was trying to press the button on the front panel when powering up esp32MX-E to set BOOT0 (as per both your instructions and datasheets). However when I am trying to communicate to it over I2C, it's timing out.

I suspect that I might not be doing the bootloader activation correctly, however I am not sure if there's any good way to test if it was indeed activated. Do you have any thoughts on whether it'd be possible for ESP32 program to check if STM32 is indeed in the bootloader (system memory) mode?

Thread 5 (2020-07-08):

Using I2C on the esp32

GeorgeSellner, 2020-07-08:
Hello,

I have been trying to use the I2C, pins 32, 33 from the Arduino IDE, and haven't had much luck. Same code, different pins, same I2C devices (BME280, RV-8803) work on a MEGA.

I haven't yet tried putting a 'scope on it to see if the code is actually doing anything. I haven't yet tried through the idf.

I was wondering if anyone else has been working with The I2C, either though the Arduino IDE or through esp-idf?

I have also been experiencing issues downloading through the CH340 under Linux, (Ubuntu 18.04). However I'm pretty sure part of the problem is I'm using a VirtualBox VM for the Linux guest on a Windows 10 host.

On a Ubuntu 14.04 laptop I can download and from Windows 10.

pauldeng, 2020-09-02:
@GeorgeSellner
Did you get I2C work? I have the same question.

pauldeng, 2020-09-14:
If you want to use I2C, you can actually use pin 4 and pin 5.
For example, I hooked up a sht30 and just initialise it as below would work:
```c
#include "Adafruit_SHT31.h"

#define I2C_SDA 4
#define I2C_SCL 5
#define SHT30_I2C_ADDR 0x44

TwoWire I2C_DEV = TwoWire(0);
Adafruit_SHT31 sht30 = Adafruit_SHT31(&I2C_DEV);

void setup()
{
  I2C_DEV.begin(I2C_SDA, I2C_SCL);

  // read the sht sensor
  if (! sht30.begin(Internal_SHT30_ADDR)) {
    Serial.println("Couldn't find Internal SHT31");
    delay(1);
  } else {
    float t= sht30.readTemperature();
    float h= sht30.readHumidity();
    Serial.print("Temp *C = "); Serial.print(internal_t); Serial.print("\t\t");
    Serial.print("Hum. % = "); Serial.println(internal_h);
  }
}
```

In my application, I need both UART and I2C to work and communicate via Ethernet. However, I can not get this board to work reliability.

I decided to move on after pulling off my hair for few days of try.

Good luck, you are on your own.

skiizo, 2020-10-23:
Same problem here.  On the scope, SCL is only getting pulled low to ~2.3V during I2C operations.  Seems that the STM32 (secondary processor) firmware is initializing that pin as a UART TX, which defaults to a high state and prevents it from being able to be pulled low for I2C.

SDA seems to still be usable, but another pin will need to be used for SCL and you will likely need to add your own pullup resistor (2.2kOhm to match the on-board one for SDA).

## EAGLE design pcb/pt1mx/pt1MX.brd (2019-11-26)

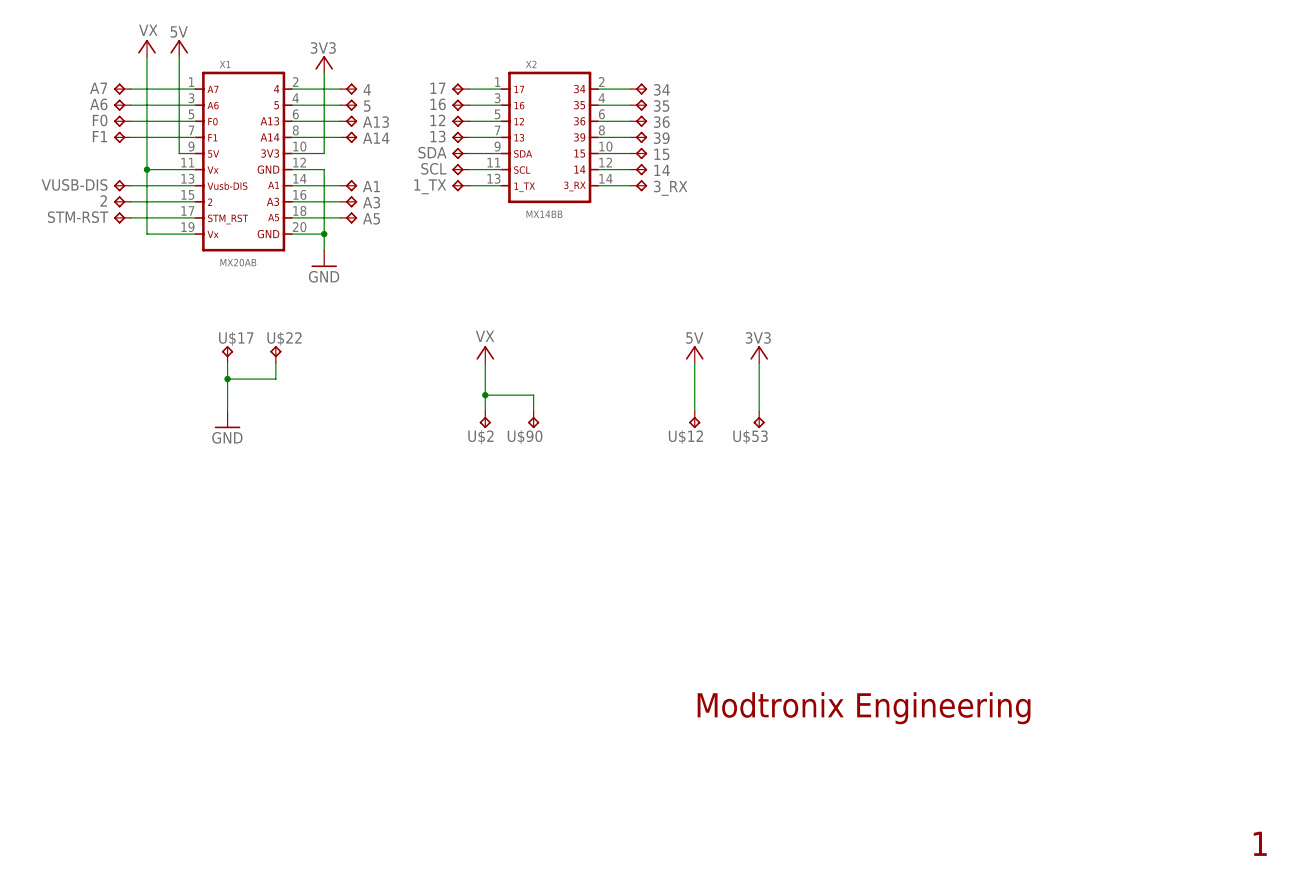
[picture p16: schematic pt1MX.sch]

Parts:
1_TX, 2, 3_RX, 4, 5, 12, 13, 14, 15, 16, 17, 34, 35, 36, 39: TPD10-D200; TP-10-D200
A1, A3, A5, A6, A7, A13, A14: TPD10-D200; TP-10-D200
F0, F1: TPD10-D200; TP-10-D200
SCL: TPD10-D200; TP-10-D200
SDA: TPD10-D200; TP-10-D200
STM-RST: TPD10-D200; TP-10-D200
U$2, U$12, U$17, U$22, U$53, U$90: TPD10-D200; TP-10-D200
VUSB-DIS: TPD10-D200; TP-10-D200
X1: MX20AB; MA10-2-NONUM
X2: MX14BB; MA07-2-NONUM

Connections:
1_TX: 1_TX.1, X2.13
2: 2.1, X1.15
3V3: U$53.1, X1.10
3_RX: 3_RX.1, X2.14
4: 4.1, X1.2
5: 5.1, X1.4
5V: U$12.1, X1.9
12: 12.1, X2.5
13: 13.1, X2.7
14: 14.1, X2.12
15: 15.1, X2.10
16: 16.1, X2.3
17: 17.1, X2.1
34: 34.1, X2.2
35: 35.1, X2.4
36: 36.1, X2.6
39: 39.1, X2.8
A1: A1.1, X1.14
A3: A3.1, X1.16
A5: A5.1, X1.18
A6: A6.1, X1.3
A7: A7.1, X1.1
A13: A13.1, X1.6
A14: A14.1, X1.8
F0: F0.1, X1.5
F1: F1.1, X1.7
GND: U$17.1, U$22.1, X1.12, X1.20
SCL: SCL.1, X2.11
SDA: SDA.1, X2.9
STM-RST: STM-RST.1, X1.17
VUSB-DIS: VUSB-DIS.1, X1.13
VX: U$2.1, U$90.1, X1.11, X1.19

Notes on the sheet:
Modtronix Engineering

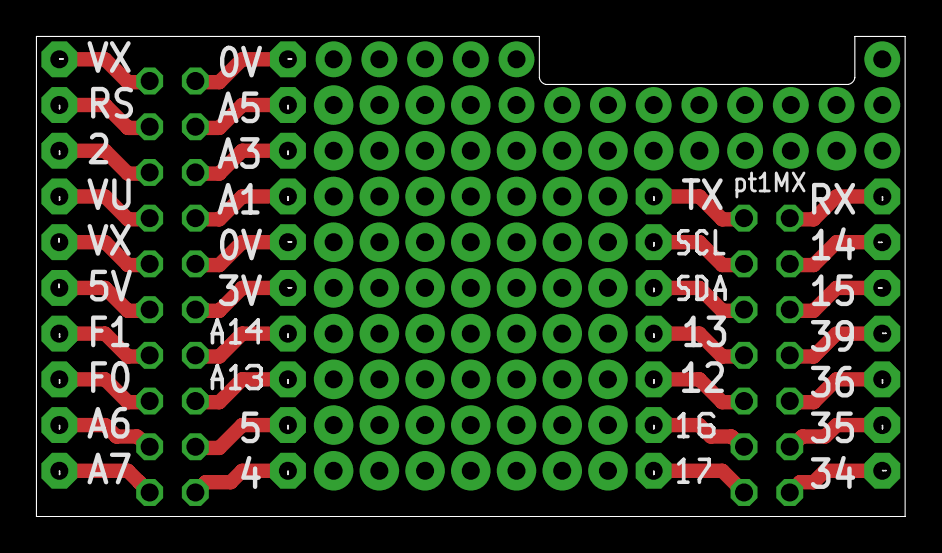
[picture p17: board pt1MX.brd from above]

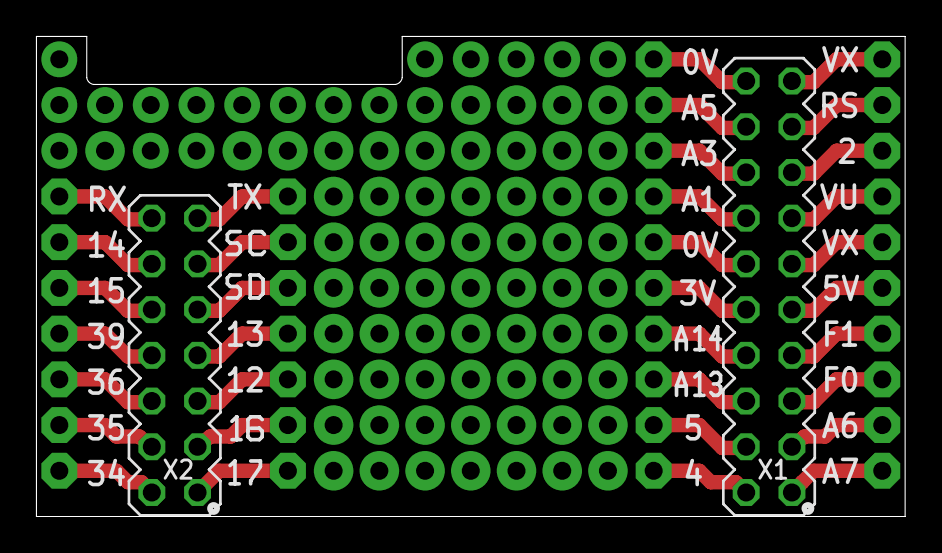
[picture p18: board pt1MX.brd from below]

Board: 2 copper layers, 48.3 x 26.7 mm, 67 parts (16 on the bottom side), 32 nets.

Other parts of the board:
U$1, U$4: S-56N
U$3: ESP32MX_20-14P_0H_REF
U$5: C-56N
U$6: D-56N
U$7, U$9, U$10, U$11, U$13: A-56N
U$8: L-56N
U$14: 4-56N
U$23: 3-56N
U$37: 3-56
U$39: 4-56
U$41, U$42, U$48, U$50, U$61, U$63, U$68, U$69: 1-56N
U$49, U$62: 6-56
U$51, U$54: S-56
U$52, U$64: 7-56N
U$55: D-56
U$57: C-56

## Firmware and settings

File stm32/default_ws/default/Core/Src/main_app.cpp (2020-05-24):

/*
 * main_app.cpp
 *
 */

/* Includes ------------------------------------------------------------------*/
#include "main.h"         //Must be first include! Contains many includes required by other code
#include "main_app.h"
#include "usart.h"



/* Defines -------------------------------------------------------------------*/
#define TX_BUF_SIZE 128

// Enable test LED on port F0
// IMPORTANT: When enabling the test LED:
// - Ensure pin F0 is configured an an output using the visual "Device Configurator Tool"
// - Set pin F0 label to "testLED" using the visual "Device Configurator Tool"
//#define ENABLE_TEST_LED

// Enable UART debug output.
// IMPORTANT: When enabling this line, ensure USART1 is enables in "Asynchronous"
// mode via the visual "Device Configurator Tool", and configured for 115200
//#define ENABLE_DEBUG_UART


/* Private variables ---------------------------------------------------------*/
uint8_t smPhyReset = 0;
/* Buffer used for reception */
uint8_t txBuf[TX_BUF_SIZE];


/**
 * Converts the upper nibble of a binary value to a hexadecimal ASCII byte.
 * For example, nzHighNibbleToAsciiHex(0xAE) will return 'A'.
 * Same as Microchip "btohexa_high()" function
 *
 * @param b The byte containing the nibble to convert
 *
 * @return The converted ASCII hex character for the given nibble
 */
__STATIC_INLINE uint8_t high_nibble_to_ascii_hex(uint8_t b) {
  b >>= 4;
  return (b > 0x9u) ? b + 'A' - 10 : b + '0';
}

/**
 * Converts the lower nibble of a binary value to a hexadecimal ASCII byte.
 * For example, nzLowNibbleToAsciiHex(0xAE) will return 'E'.
 * Same as Microchip "btohexa_low()" function
 *
 * @param b The byte containing the nibble to convert
 *
 * @return The converted ASCII hex character for the given nibble
 */
__STATIC_INLINE uint8_t low_nibble_to_ascii_hex(uint8_t b) {
  b &= 0x0F;
  return (b > 9u) ? b + 'A' - 10 : b + '0';
}


/**
 * Initialization called before HAL init
 */
void mainAppInitPreHAL(void) {

 // Debug initialization before HAL init
 //My_Debug_Init_Pre_HAL();
}


/**
 * Initialization called after HAL init
 */
void mainAppInit() {
	smPhyReset = 0;						// PHY reset state

	// Reset PHY
	HAL_GPIO_WritePin(resetPHY_GPIO_Port, resetPHY_Pin, GPIO_PIN_RESET);
}

/**
 * Called just before main loop. This will be called after
 * all other initialization.
 */
void mainAppPreLoop() {
	// Turn test LED on
#ifdef ENABLE_TEST_LED
	HAL_GPIO_WritePin(testLED_GPIO_Port, testLED_Pin, GPIO_PIN_SET);
#endif

#ifdef ENABLE_DEBUG_UART
	txBuf[0] = 'H';
	txBuf[1] = 'i';
	txBuf[2] = '\r';
	txBuf[3] = '\n';
	HAL_UART_Transmit(&huart1, &txBuf[0], 4, 100);
#endif
}

/* My Main Loop */
void mainAppLoop() {
	static uint32_t senseCnt = 0;
	static uint32_t tmrSense = 0;
	static uint32_t tmrTemp = 0;

	// Refresh IWDG watchdog down-counter to default value
	//LL_IWDG_ReloadCounter(IWDG);

	// A reset signal is applied to the ESP32
	if (HAL_GPIO_ReadPin(resetESP_GPIO_Port, resetESP_Pin) == 0) {
		smPhyReset = 0;
		senseCnt = 0;

		// Reset PHY
		HAL_GPIO_WritePin(resetPHY_GPIO_Port, resetPHY_Pin, GPIO_PIN_RESET);

		// Turn test LED on
		#ifdef ENABLE_TEST_LED
		HAL_GPIO_WritePin(testLED_GPIO_Port, testLED_Pin, GPIO_PIN_SET);
		#endif
	}
	// No reset signal is applied to the ESP32
	else {
		// Just came out of reset, set state to start looking for toggling GPIO0
		if (smPhyReset == 0) {
			// To save code space, do not use "tmrSense = HAL_GetTick() + 3;". Will be done below on first check of tmrSense
			tmrSense = 0;

			smPhyReset++;
		}
	}

	// Look for toggling GPIO0, which will be when the ESP32 start outputting PHY clock on it
	// If we find 200 pulses within 3ms, we take the PHY out of reset
	if (smPhyReset == 1) {

		// If we have been in this state for longer than tmrSense(3ms), reset
		if (HAL_GetTick() >= tmrSense) {
			#ifdef ENABLE_DEBUG_UART
			txBuf[0] = 'R';
			txBuf[1] = 'S';
			txBuf[2] = 'T';
			txBuf[3] = '\n';
			HAL_UART_Transmit(&huart1, &txBuf[0], 4, 100);
			#endif

			// Put this AFTER UART output above, because it will delay for a long time
			tmrSense = HAL_GetTick() + 3;	// Check again in 3ms
			senseCnt = 0;	// Reset
		}

		// A pulse was detected on the GPIO0 pin
		if(__HAL_GPIO_EXTI_GET_IT(phyOscSense_Pin) != 0) {
			__HAL_GPIO_EXTI_CLEAR_IT(phyOscSense_Pin);
			senseCnt++;

			// Look for 200 clock cycles, should take less than 1ms
			if (senseCnt > 200) {
				// Turn test LED off
				#ifdef ENABLE_TEST_LED
				HAL_GPIO_WritePin(testLED_GPIO_Port, testLED_Pin, GPIO_PIN_RESET);
				#endif

				// Enable PHY
				HAL_GPIO_WritePin(resetPHY_GPIO_Port, resetPHY_Pin, GPIO_PIN_SET);

				#ifdef ENABLE_DEBUG_UART
				txBuf[0] = 'P';
				txBuf[1] = 'H';
				txBuf[2] = 'Y';
				txBuf[3] = '\n';
				HAL_UART_Transmit(&huart1, &txBuf[0], 4, 100);
				#endif

				smPhyReset++;
			}
		}
	}
	else if (smPhyReset == 2) {
		// For testing only
		#ifdef ENABLE_DEBUG_UART
		if(__HAL_GPIO_EXTI_GET_IT(phyOscSense_Pin) != 0) {
			__HAL_GPIO_EXTI_CLEAR_IT(phyOscSense_Pin);
			senseCnt++;
		}

		if (HAL_GetTick() > tmrTemp) {
			tmrTemp = HAL_GetTick() + 250;	// Every second

			txBuf[0] = high_nibble_to_ascii_hex((uint8_t)senseCnt);
			txBuf[1] = low_nibble_to_ascii_hex((uint8_t)senseCnt);
			txBuf[2] = '\n';
			HAL_UART_Transmit(&huart1, &txBuf[0], 3, 100);
		}
		#endif
	}
}

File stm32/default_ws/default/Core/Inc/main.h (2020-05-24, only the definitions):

#define testLED_Pin GPIO_PIN_0
#define testLED_GPIO_Port GPIOF
#define userButton_Pin GPIO_PIN_0
#define userButton_GPIO_Port GPIOA
#define resetPHY_Pin GPIO_PIN_2
#define resetPHY_GPIO_Port GPIOA
#define resetESP_Pin GPIO_PIN_4
#define resetESP_GPIO_Port GPIOA
#define phyOscSense_Pin GPIO_PIN_1
#define phyOscSense_GPIO_Port GPIOB

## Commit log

2019-11-19 Update and rename esp32MX-E/readme.md to Doc/readme.md
2019-11-26 Added gitignore and prototype PCBs
    [pt1MX.brd, pt1MX.sch, pt2MX.brd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]
2019-11-26 Improved PCB images
2019-11-27 Update readme.md
    Added "fpan-mxe" pcb and image
2019-11-27 Added esp32MX-E Schematics
2020-04-04 Arduino and Documentation
2020-04-05 Added Arduino Examples
2020-04-06 Arduino examples
2020-05-24 Added STM32 source code
    [CMSIS-DAP.cfg]

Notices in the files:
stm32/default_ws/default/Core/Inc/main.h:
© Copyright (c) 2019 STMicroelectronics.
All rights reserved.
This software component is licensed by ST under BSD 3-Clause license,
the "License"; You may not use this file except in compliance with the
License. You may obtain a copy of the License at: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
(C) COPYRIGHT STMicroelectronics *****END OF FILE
